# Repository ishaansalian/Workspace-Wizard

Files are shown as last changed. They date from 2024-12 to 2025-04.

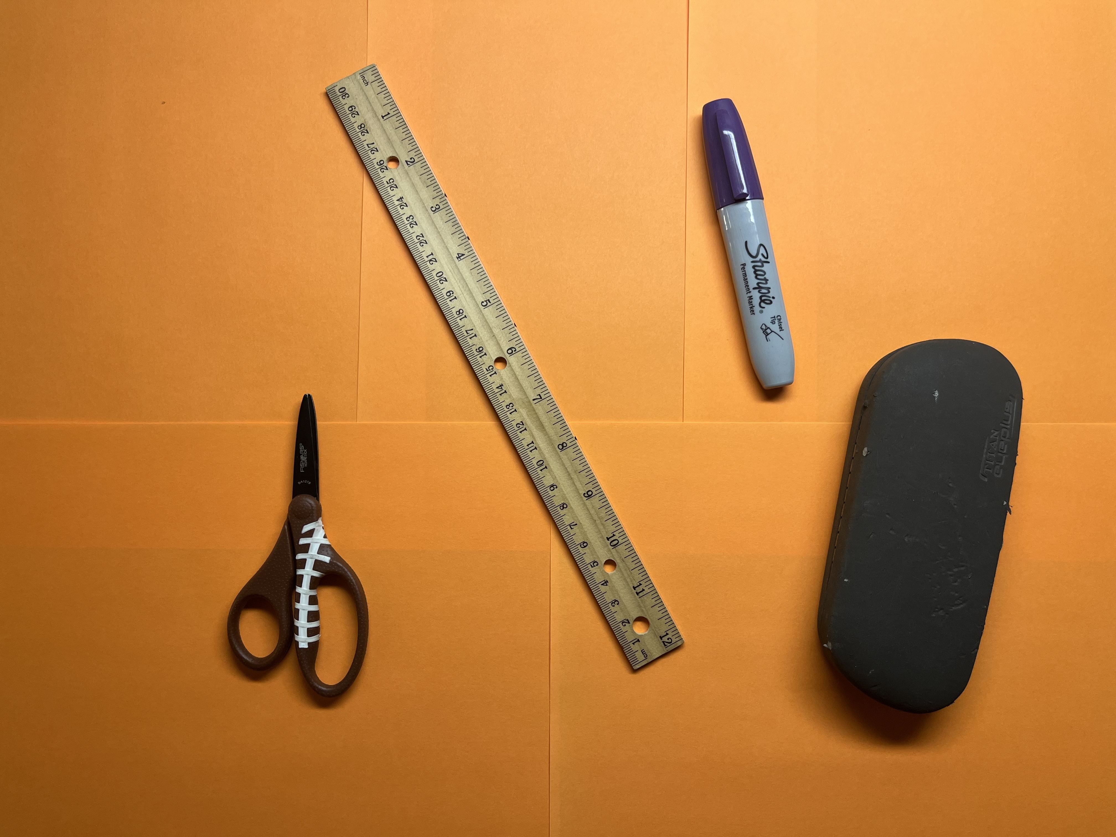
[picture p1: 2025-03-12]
desk copy.jpg

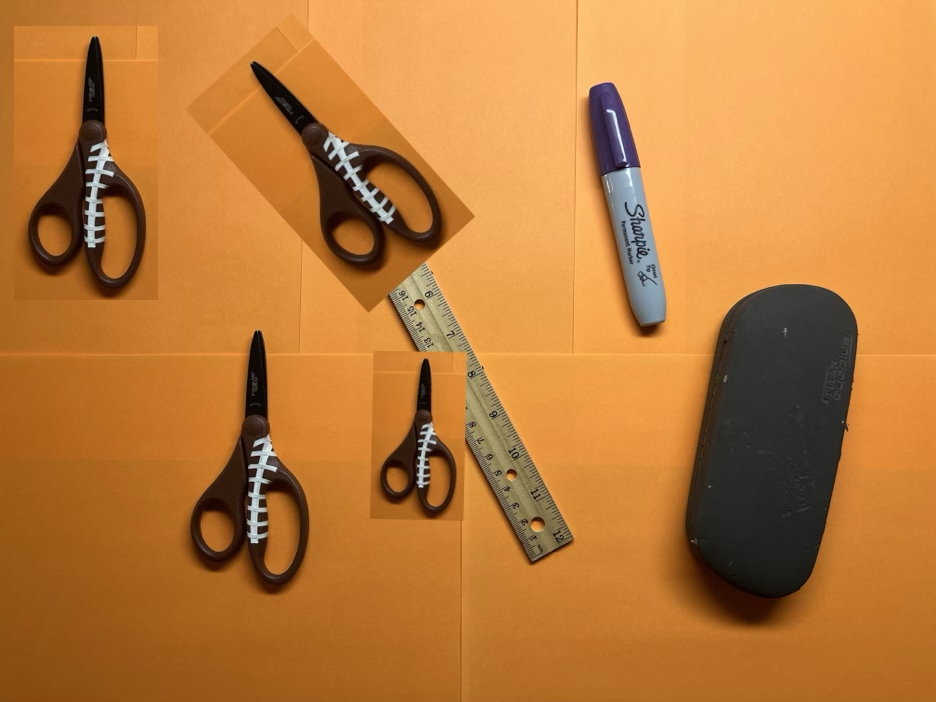
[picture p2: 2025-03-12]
desk3.jpg

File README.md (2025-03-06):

# Workspace Wizard

**Team Members:**  
- Ishaan Salian  
- Aryaman Ghura 
- Kavya Manchanda  
- Mary Esenther

**Project Overview**  
Workspace Wizard is an autonomous desk organization system designed to optimize workspace management by identifying, sorting, and organizing objects on a desk. The system uses a combination of hardware and software to detect object positions, plan efficient placement paths, and execute movements to organize objects with high precision.

**Key Features:**  
- **Object Detection & Recognition:** The system uses a camera and machine learning models to identify and track objects on the desk.
- **Pathfinding Algorithm:** The robot calculates optimal paths for organizing objects, avoiding obstacles and ensuring an efficient layout.
- **Autonomous Movement:** The robot uses motors and tracks to move objects into predefined positions while respecting boundaries and object types.
- **Task Automation:** The robot performs "knolling" (arranging objects neatly and systematically) by aligning objects with a target orientation and spacing.

**Technologies Used:**  
- **Hardware:**  
  - Nvidia Jetson (for processing and computation)  
  - Servo motors and tracks (for movement)
  - Custom PCB (for controls)
  - USB Camera (for object detection and tracking)  
  - Power management system (for optimal battery usage)  
- **Software:**  
  - Python (for control logic and algorithms)  
  - OpenCV (for computer vision tasks)

**References:**  
- Hu, Y., Zhang, Z., Zhu, X., Liu, R., Philippe Martin Wyder, & Lipson, H. (2023). Knolling bot: Learning robotic object arrangement from tidy demonstrations. https://api.semanticscholar.org/CorpusID:268513198

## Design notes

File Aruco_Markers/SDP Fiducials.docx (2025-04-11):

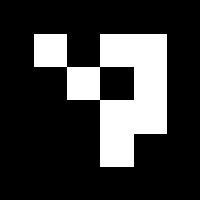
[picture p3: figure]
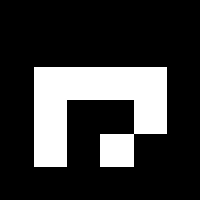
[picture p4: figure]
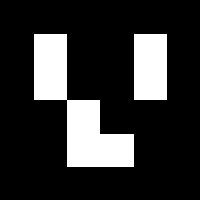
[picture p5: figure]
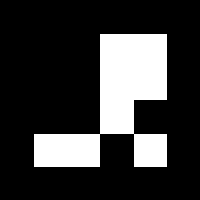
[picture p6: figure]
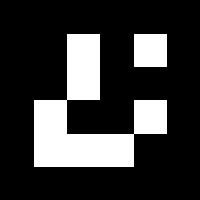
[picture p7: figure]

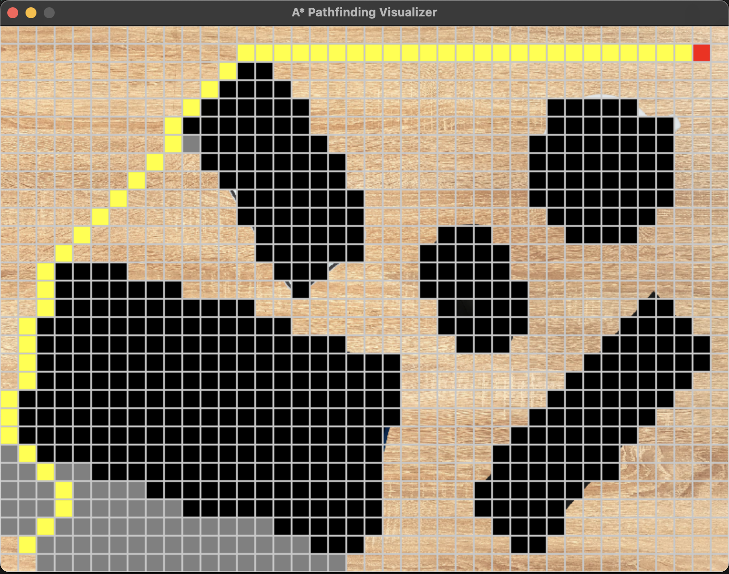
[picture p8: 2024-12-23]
Path-Planning/a-star-screenshot.jpg

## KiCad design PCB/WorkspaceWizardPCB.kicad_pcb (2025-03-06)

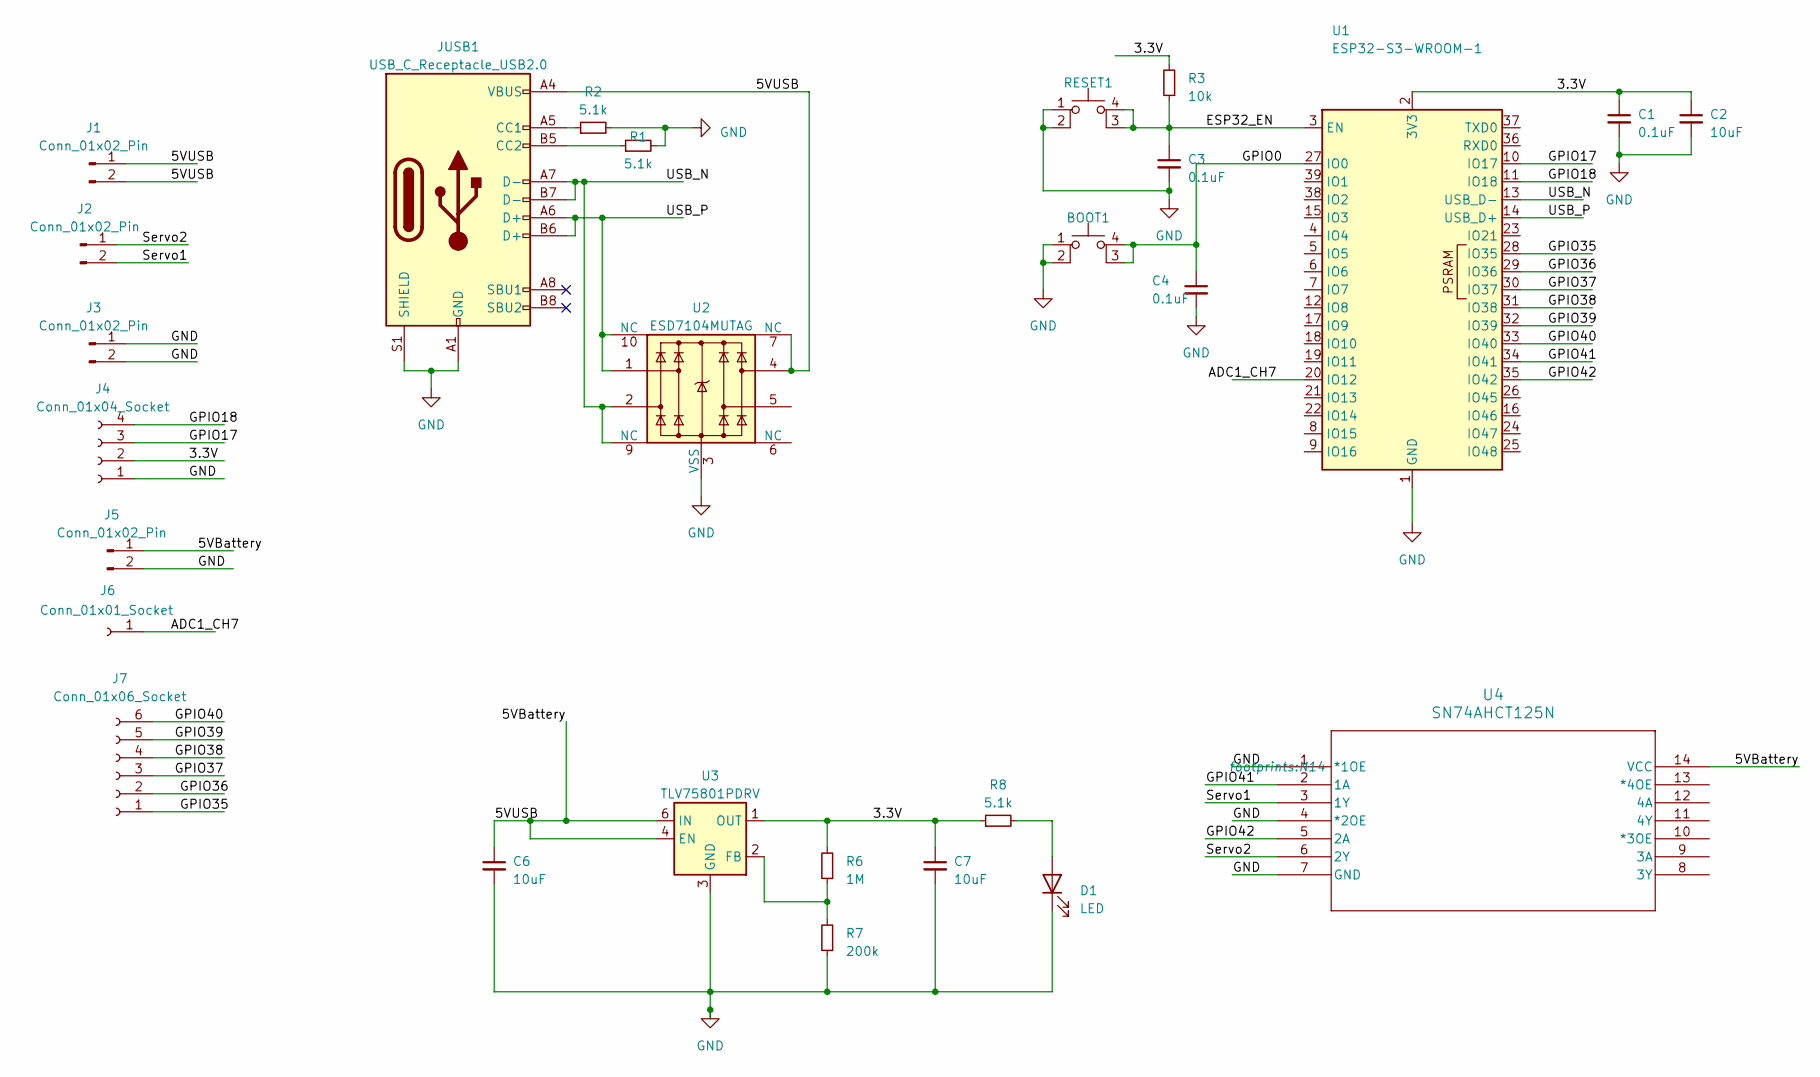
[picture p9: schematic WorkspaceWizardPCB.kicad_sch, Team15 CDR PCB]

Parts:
BOOT1: SW_SPST_PTS810
C1, C3, C4: 0.1uF; C_0603_1608Metric; LCSC C701321
C2, C6, C7: 10uF; C_0603_1608Metric; LCSC C38898
D1: LED; LED_0603_1608Metric; LCSC C9900030205
J1, J2, J3, J5: Conn_01x02_Pin; PinHeader_1x02_P2.54mm_Vertical
J4: Conn_01x04_Socket; PinSocket_1x04_P2.54mm_Vertical
J6: Conn_01x01_Socket; PinSocket_1x01_P2.54mm_Vertical
J7: Conn_01x06_Socket; PinSocket_1x06_P2.54mm_Vertical
JUSB1: USB_C_Receptacle_USB2.0; USB_C_Receptacle_GCT_USB4105-xx-A_16P_TopMnt_Horizontal; LCSC C3020560
R1, R2, R8: 5.1k; R_0603_1608Metric; LCSC C881139
R3: 10k; R_0603_1608Metric; LCSC C881132
R6: 1M; R_0603_1608Metric; LCSC C22935
R7: 200k; R_0603_1608Metric; LCSC C881135
RESET1: SW_SPST_PTS810
U1: ESP32-S3-WROOM-1; LCSC C2913201
U2: ESD7104MUTAG; Diodes_UDFN-10_1.0x2.5mm_P0.5mm; LCSC C1980462
U3: TLV75801PDRV; WSON-6-1EP_2x2mm_P0.65mm_EP1x1.6mm; LCSC C2876308
U4: SN74AHCT125N; N14

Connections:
/3.3V: C1.1, C2.1, C7.1, J4.2, R3.2, R6.2, R8.1, U1.2 (3V3), U3.1 (OUT)
/5VBattery: C6.1, J1.1, J1.2, J5.1, JUSB1.A4 (VBUS), JUSB1.A9 (VBUS), JUSB1.B4 (VBUS), JUSB1.B9 (VBUS), U2.4, U2.7 (NC), U3.4 (EN), U3.6 (IN), U4.14 (VCC)
/ADC1_CH7: J6.1, U1.20 (IO12)
/ESP32_EN: C3.1, R3.1, RESET1.3 (K), RESET1.4 (A), U1.3 (EN)
/GPIO0: BOOT1.3 (K), BOOT1.4 (A), C4.1, U1.27 (IO0)
/GPIO17: J4.3, U1.10 (IO17)
/GPIO18: J4.4, U1.11 (IO18)
/GPIO35: J7.1, U1.28 (IO35)
/GPIO36: J7.2, U1.29 (IO36)
/GPIO37: J7.3, U1.30 (IO37)
/GPIO38: J7.4, U1.31 (IO38)
/GPIO39: J7.5, U1.32 (IO39)
/GPIO40: J7.6, U1.33 (IO40)
/GPIO41: U1.34 (IO41), U4.2 (1A)
/GPIO42: U1.35 (IO42), U4.5 (2A)
/Servo1: J2.2, U4.3 (1Y)
/Servo2: J2.1, U4.6 (2Y)
/USB_N: JUSB1.A7 (D-), JUSB1.B7 (D-), U1.13 (USB_D-), U2.2, U2.9 (NC)
/USB_P: JUSB1.A6 (D+), JUSB1.B6 (D+), U1.14 (USB_D+), U2.1, U2.10 (NC)
GND: BOOT1.1, BOOT1.2, C1.2, C2.2, C3.2, C4.2, C6.2, C7.2, D1.1 (K), J3.1, J3.2, J4.1, J5.2, JUSB1.A1 (GND), JUSB1.A12 (GND), JUSB1.B1 (GND), JUSB1.B12 (GND), JUSB1.S1 (SHIELD), R1.2, R2.2, R7.1, RESET1.1, RESET1.2, U1.1 (GND), U1.40 (GND), U1.41 (GND), U2.3 (VSS), U2.8 (VSS), U3.3 (GND), U3.7 (GND), U4.1 (*1OE), U4.4 (*2OE), U4.7 (GND)
unnamed: D1.2 (A), R8.2
unnamed: JUSB1.A5 (CC1), R2.1
unnamed: JUSB1.B5 (CC2), R1.1
unnamed: R6.1, R7.2, U3.2 (FB)

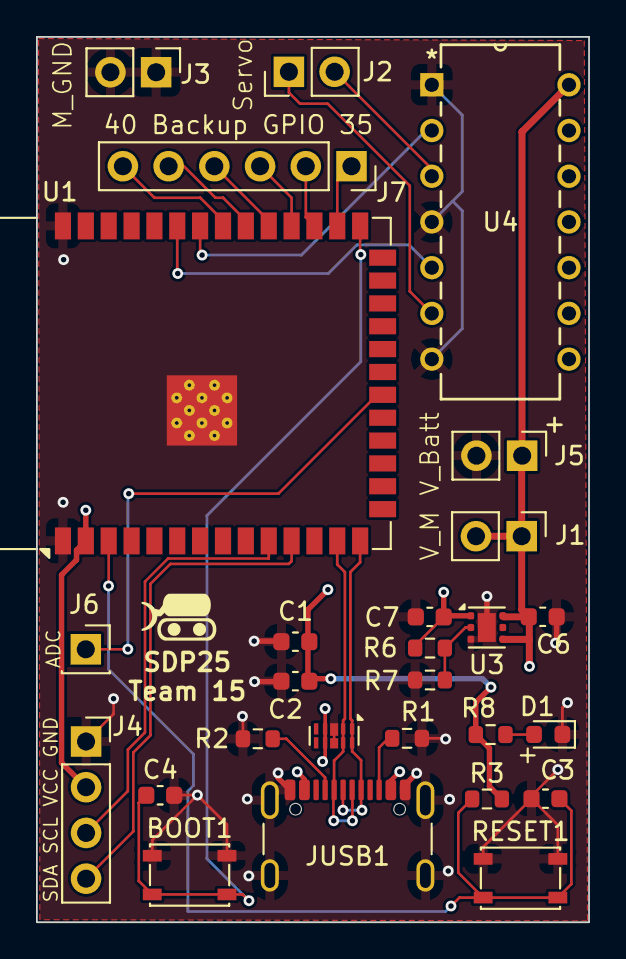
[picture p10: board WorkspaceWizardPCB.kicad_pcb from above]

Board: 4 copper layers, 30.7 x 49.2 mm, 27 parts (0 on the bottom side), 24 nets.

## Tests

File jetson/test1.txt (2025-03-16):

gst_pipeline = (
    "nvarguscamerasrc ! "
    "video/x-raw(memory:NVMM), width=1280, height=720, framerate=30/1, format=NV12 ! "
    "nvvidconv ! "
    "video/x-raw, format=BGRx ! "
    "videoconvert ! "
    "video/x-raw, format=BGR ! "
    "appsink"
)

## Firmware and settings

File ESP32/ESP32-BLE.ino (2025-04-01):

#include <BLEDevice.h>
#include <BLEServer.h>
#include <BLEUtils.h>
#include <BLE2902.h>
#include <ESP32Servo.h>
#include <Wire.h>
#include <Adafruit_GFX.h>
#include <Adafruit_SSD1306.h>

// UUIDs for BLE Service and Characteristic
#define SERVICE_UUID "4fafc201-1fb5-459e-8fcc-c5c9c331914b"
#define CHARACTERISTIC_UUID "beb5483e-36e1-4688-b7f5-ea07361b26a8"

BLEServer *pServer;
BLECharacteristic *pCharacteristic;
bool deviceConnected = false;
unsigned long lastBatteryUpdate = 0;

// Servo Pins
#define LEFT_SERVO_PIN 41
#define RIGHT_SERVO_PIN 42

Servo leftServo;
Servo rightServo;

// OLED I2C Pins
#define OLED_SDA 18
#define OLED_SCL 17

// OLED Display Setup
#define SCREEN_WIDTH 128
#define SCREEN_HEIGHT 64
#define OLED_RESET -1
Adafruit_SSD1306 display(SCREEN_WIDTH, SCREEN_HEIGHT, &Wire, OLED_RESET);

// Battery Measurement
#define BATTERY_PIN 12
#define MAX_ADC_READING 4095
#define REF_VOLTAGE 3.3
#define NUM_SAMPLES 10
#define BATTERY_UPDATE_MS 5000

#define BATTERY_LOW_VOLTAGE 3.3  // Warning threshold
#define BATTERY_CRITICAL_VOLTAGE 3.0 // Below this, battery is unsafe to discharge further
#define MIN_BATTERY_VOLTAGE 3.0
#define MAX_BATTERY_VOLTAGE 4.2

// Voltage Divider Ratio: (R1 + R2) / R2 => (1.8K + 3.3K) / 1.8K = 5.1 / 1.8
#define VOLTAGE_DIVIDER_RATIO (5.1 / 3.3) // Need to be updated

// Define maximum battery voltage for percentage calculation
#define MAX_BATTERY_VOLTAGE 3.7

// Struct to hold battery data
struct BatteryData {
    float voltage;
    int percentage;
};

// Function to get battery voltage and percentage
BatteryData getBatteryData() {
    int totalADC = 0;
    for (int i = 0; i < NUM_SAMPLES; i++) {
        totalADC += analogRead(BATTERY_PIN);
        delay(5);
    }

    // Calculate the average ADC value
    float avgADC = totalADC / (float)NUM_SAMPLES;
    float voltageAtDivider = (avgADC / MAX_ADC_READING) * REF_VOLTAGE;
    float batteryVoltage = voltageAtDivider * VOLTAGE_DIVIDER_RATIO;

    // Battery percentage calculation (mapped between 3.0V and 4.2V)
    float batteryPercentage = ((batteryVoltage - MIN_BATTERY_VOLTAGE) / (MAX_BATTERY_VOLTAGE - MIN_BATTERY_VOLTAGE)) * 100.0;

    // Ensure percentage stays in valid range
    if (batteryPercentage > 100.0) batteryPercentage = 100;
    if (batteryPercentage < 0.0) batteryPercentage = 0;

    return {batteryVoltage, (int)batteryPercentage};
}

void updateDisplay(const String& message = "") {
    BatteryData battery = getBatteryData();

    display.clearDisplay();
    display.setTextSize(1);
    display.setTextColor(WHITE);
    display.setCursor(8, 5);  
    display.println("Workspace Wizard :D");
    
    // Display battery percentage and voltage
    display.setCursor(10, 25);
    display.print("Battery: ");
    display.print((int)battery.percentage);
    display.print("%, ");
    display.print(battery.voltage, 2); // Display with 2 decimal places
    display.print("V");

    // Display warning if battery is low
    if (battery.voltage <= BATTERY_LOW_VOLTAGE) {
        display.setCursor(10, 25);
        display.setTextColor(WHITE, BLACK);
        display.println("LOW BATTERY!");
    }

    if (battery.voltage <= BATTERY_CRITICAL_VOLTAGE) {
        display.setCursor(10, 25);
        display.setTextColor(WHITE, BLACK);
        display.println("CRITICAL! CHARGE NOW!");
    }

    display.setCursor(10, 35);
    display.print("BLE: ");
    display.print(deviceConnected ? "ON" : "OFF");

    if (!message.isEmpty()) {
        display.setCursor(10, 45);
        display.print(message);
    }

    display.display();
}

// Function to stop both servos
void stop() {
  leftServo.write(90);
  rightServo.write(90);
}

// Function to move forward for a short duration
void moveForward() {
  leftServo.write(120);
  rightServo.write(60);
  delay(112.5);           // Increased duration
  stop();
}

void moveBackward() {
  leftServo.write(60);
  rightServo.write(120);
  delay(112.5);
  stop();
}

// Function to turn left on the spot for a short duration
void turnLeft() {
  leftServo.write(68);
  rightServo.write(68);
  delay(1045); // Adjusted for approximately 90° turn
  stop();
}

void turnRight() {
  leftServo.write(112);
  rightServo.write(112);
  delay(1045); // Adjusted for approximately 90° turn
  stop();
}

void smallTurnLeft() {
  leftServo.write(75);
  rightServo.write(75);
  delay(170); // Adjusted for approximately 90° turn
  stop();
}

void smallTurnRight() {
  leftServo.write(105);
  rightServo.write(105);
  delay(170); // Adjusted for approximately 90° turn
  stop();
}

void DemoSpinR() {
  moveForward();
  turnRight();
  moveForward();
  turnRight();
  moveForward();
  turnRight();
  moveForward();
  turnRight();
  stop();
}

void DemoSpinL() {
  moveForward();
  turnLeft();
  moveForward();
  turnLeft();
  moveForward();
  turnLeft();
  moveForward();
  turnLeft();
  stop();
}

class MyServerCallbacks : public BLEServerCallbacks {
    void onConnect(BLEServer* pServer) {
        deviceConnected = true;
        updateDisplay();
    }
    void onDisconnect(BLEServer* pServer) {
        deviceConnected = false;
        updateDisplay();
        BLEDevice::startAdvertising();
    }
};

class MyCallbacks : public BLECharacteristicCallbacks {
    void onWrite(BLECharacteristic *pCharacteristic) {
        String receivedValue = pCharacteristic->getValue().c_str();

        if (receivedValue == "finished" || receivedValue == "stuck") {
            Serial.println("Status: " + receivedValue);
            updateDisplay(receivedValue);
            return;
        }

        if (receivedValue.length() < 1) return;

        int repeatCount = 1;
        char commandChar;
        if (isdigit(receivedValue[0])) {
            repeatCount = receivedValue.substring(0, receivedValue.length() - 1).toInt();
            commandChar = receivedValue[receivedValue.length() - 1];
        } else {
            commandChar = receivedValue[0];
        }

        for (int i = 0; i < repeatCount; i++) {
            switch (commandChar) {
                case 'F':
                    Serial.println("Moving Forward");
                    moveForward();
                    break;
                case 'B':
                    Serial.println("Moving Backward");
                    moveBackward();
                    break;
                case 'L':
                    Serial.println("Turning Left");
                    turnLeft();
                    break;
                case 'R':
                    Serial.println("Turning Right");
                    turnRight();
                    break;
                case 'O':
                    Serial.println("Spinning Left");
                    DemoSpinL();
                    break;
                case 'P':
                    Serial.println("Spinning Right");
                    DemoSpinR();
                    break;
                case 'N':
                    Serial.println("Adjusting Left");
                    smallTurnLeft();
                    break;
                case 'M':
                    Serial.println("Adjusting Right");
                    smallTurnRight();
                    break;
                default:
                    Serial.println("Unknown command, stopping");
                    stop();
                    return;
            }
        }
    }
};

void setup() {
    Serial.begin(115200);
    Wire.begin(OLED_SDA, OLED_SCL);
    if (!display.begin(SSD1306_SWITCHCAPVCC, 0x3C)) {
        Serial.println("SSD1306 allocation failed");
        for (;;);
    }
    analogReadResolution(12);
    updateDisplay();
    leftServo.attach(LEFT_SERVO_PIN);
    rightServo.attach(RIGHT_SERVO_PIN);
    stop();
    BLEDevice::init("ESP32_Robot");
    pServer = BLEDevice::createServer();
    pServer->setCallbacks(new MyServerCallbacks());
    BLEService *pService = pServer->createService(SERVICE_UUID);
    pCharacteristic = pService->createCharacteristic(
        CHARACTERISTIC_UUID,
        BLECharacteristic::PROPERTY_READ |
        BLECharacteristic::PROPERTY_WRITE
    );
    pCharacteristic->setCallbacks(new MyCallbacks());
    pService->start();
    BLEAdvertising *pAdvertising = BLEDevice::getAdvertising();
    pAdvertising->start();
    Serial.println("Waiting for a client connection...");
}

void loop() {
    unsigned long currentMillis = millis();
    if (currentMillis - lastBatteryUpdate >= BATTERY_UPDATE_MS) {
        updateDisplay();
        lastBatteryUpdate = currentMillis;
    }
}

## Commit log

2024-11-24 Create PCB
2024-11-24 added PCB
    [Robot.kicad_pcb, Robot.kicad_sch]
2025-03-06 Update and rename Movement.ino to ESP32-BLE.ino
2025-03-06 added KiCad files
    [WorkspaceWizardPCB.kicad_pcb, WorkspaceWizardPCB.kicad_sch]
2025-03-10 Bot tracking
    Tracks two fiducials to crop and flatten output image, and detects robot within that image by its corners. The corners are printed out, and the cropped image is saved to the file system. Don't leave 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
2025-03-12 Updated to auto-detect the ESP32 by its name
2025-03-13 updated to auto-detect the ESP32 by its name and find address
2025-03-13 Update and rename fiducial_to_robot_movement.py to ESP32/fiducial_to_robot_movement.py
2025-03-13 updated to print battery along with voltage
2025-03-31 Calibration checkerboard
    Dimensions are 12x8, which is listed as 11x7 in the code. If this is ever changed, we'll need to match the size with a new chessboard.
